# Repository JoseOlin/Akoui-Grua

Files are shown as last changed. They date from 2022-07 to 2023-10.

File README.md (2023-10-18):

# Akoui Transfer Crane

The *Akoui* crane is [Olin Robotics](https://www.olinrobotics.com)' proposal for independent transfer of people with disabilities.

Person moving from wheelchair to bed with electronic assist lift

The Akoui belongs to the **Olin Autonomy** project; an ecosystem of assistive devices to allow independent living for people with disabilities, even severe ones, who can control a joystick.

---

The Akoui crane is made up of 3 modules:

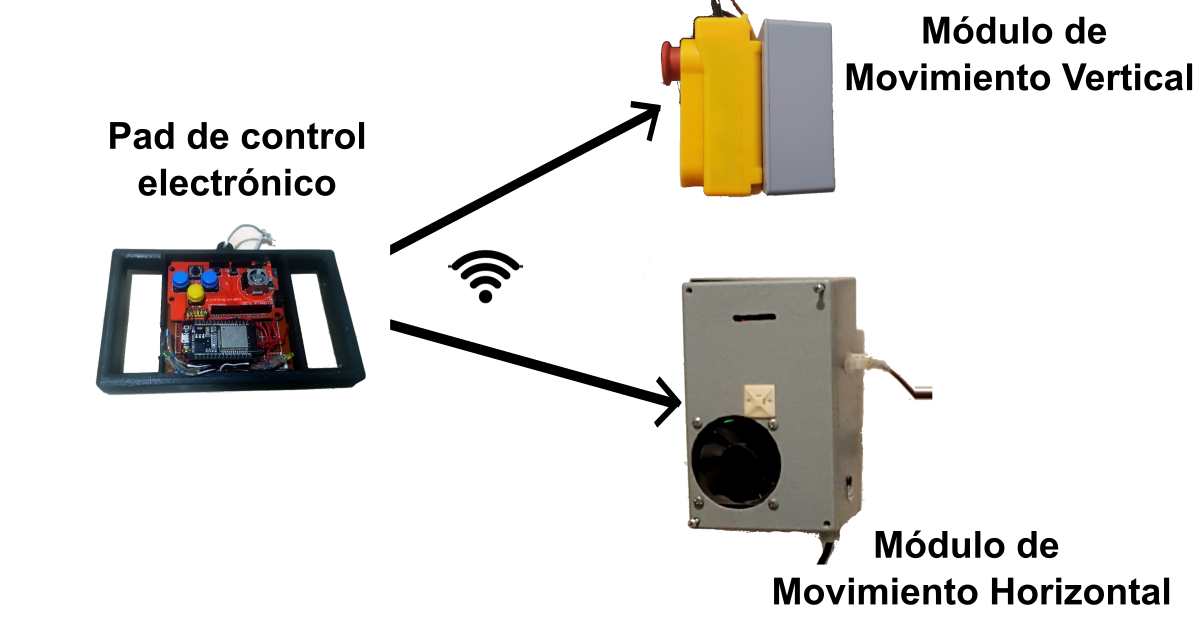
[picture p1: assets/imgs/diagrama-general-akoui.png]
Diagrama General Akoui


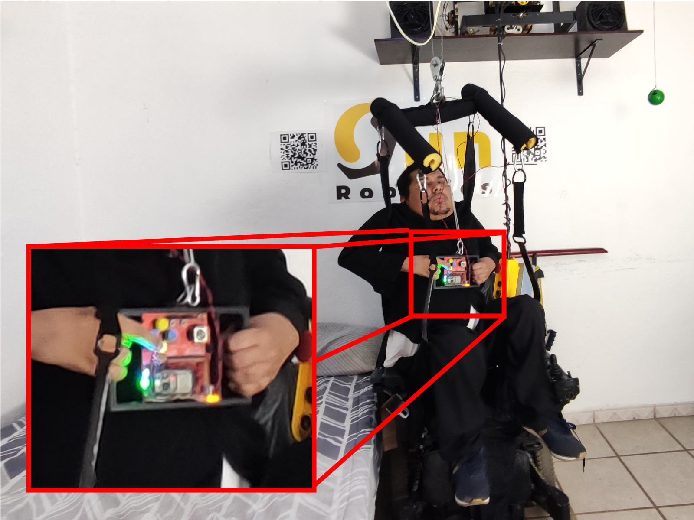
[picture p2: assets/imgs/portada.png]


1. **Vertical motion module**. Electronically controls the vertical movement of the crane. It has an ESP8266 module (WeMos D1 Mini).

2. **Horizontal movement module**. Electronically controls the horizontal movement of the crane. It has an ESP8266 module (WeMos D1 Mini).

3. **Control pad**. Sends movement commands to the respective modules. Uses an ESP-32 module (ESP-WROOM-32).

There is a [tutorial to build it](https://olinrobotics.com/blog/23-09_akoui-construccion-control-pad/p) on the Olin Robotics blog (in Spanish).

---
The Akoui is Free Hardware and Software. We believe in a world where technology for independent living is accessible and free.

If you want to support the development of Akoui, join the [Dojo of Autonomy on Patreon](https://www.patreon.com/olinrobotics?fan_landing=true).

**¡Hasta la Autonomía, Siempre!**
*Always to Autonomy!*

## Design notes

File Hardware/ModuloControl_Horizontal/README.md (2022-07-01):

El módulo de control horizontal se compone de 

- Un regulador de voltaje de 24 a 3.3V
- Un Driver DC MC33926
-

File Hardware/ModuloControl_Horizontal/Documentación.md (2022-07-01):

# Grúa Incorporación

La fuente de poder es de 24V. Conectada a:

	+ Puente H para el motor.
	+ Potenciómetro -> Abanico de la caja
	+ Regulalador de voltaje LM2596

El regulador de voltaje LM2596 recibe 24V en In y entrega 3.3V en Out). Está conectado a:

+ Módulo ESP01

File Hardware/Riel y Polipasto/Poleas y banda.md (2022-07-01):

[Polea Dentada Gt2 60 Dientes 8mm, Ideal Para Nema 23 Cnc,](https://articulo.mercadolibre.com.mx/MLM-582137986-polea-dentada-gt2-60-dientes-8mm-ideal-para-nema-23-cnc-_JM)

[Polea Dentada Gt2 20 Dientes 8mm Nema 23 Impresora3d Cnc 1pz](https://articulo.mercadolibre.com.mx/MLM-585223447-polea-dentada-gt2-20-dientes-8mm-nema-23-impresora3d-cnc-1pz-_JM)

[Polea Pasiva Gt2 20 Dientes Agujero 3mm, Cnc, 3d Print](https://articulo.mercadolibre.com.mx/MLM-585659330-polea-pasiva-gt2-20-dientes-agujero-3mm-cnc-3d-print-_JM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)

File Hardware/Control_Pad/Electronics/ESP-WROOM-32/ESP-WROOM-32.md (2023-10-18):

# ESP-WROOM-32

https://randomnerdtutorials.com/getting-started-with-esp32/

## Pinout

ESP32-Pinout


https://circuits4you.com/2018/12/31/esp32-devkit-esp32-wroom-gpio-pinout/

### Arduino Framework
En Arduino el pin corresponde con el GPIO. 

| Etiqueta	| GPIO		| Pin Framework Arduino |
|---|---|---|
|D2			|	GPIO2 	|  2 	|
|D4			|	GPIO4 	|  4 	|
|D5			|	GPIO5 	|  5 	|
|D18			|	GPIO18	|  18 	|
|D19			|	GPIO19 	|  19 	|
| ...		|	...		|  ...	|

	pinMode(4, OUTPUT);

### NOTAS:

El **GPIO12** (**D12** en el etiquetado de la tablilla) **no debe estar en alto en el arranque**, pues causa conflicto de escritura en la memoria Flash.

	if(Serial.available() > 0)
	  {
	    char c = Serial.read();
	    
	    if (c == 'o')
	    {
	      Serial.println("Activando subida...");
	      String subir_activar = serverNameV + "/subir/1";
	      httpRequest(subir_activar);
	      
	    }
	    else if(c == 'f')
	    {
	      Serial.println("Desactivando subida...");
	      String subir_desactivar = serverNameV + "/subir/0";
	      httpRequest(subir_desactivar);
	    }
	}

## How to power

https://techexplorations.com/guides/esp32/begin/power/

## PlatformIO Board name
esp32dev

[env:esp_wroom_32]
platform = espressif32
board = esp32dev
framework = arduino
monitor_speed = 115200

## Hall Effect Sensor

https://randomnerdtutorials.com/esp32-hall-effect-sensor/

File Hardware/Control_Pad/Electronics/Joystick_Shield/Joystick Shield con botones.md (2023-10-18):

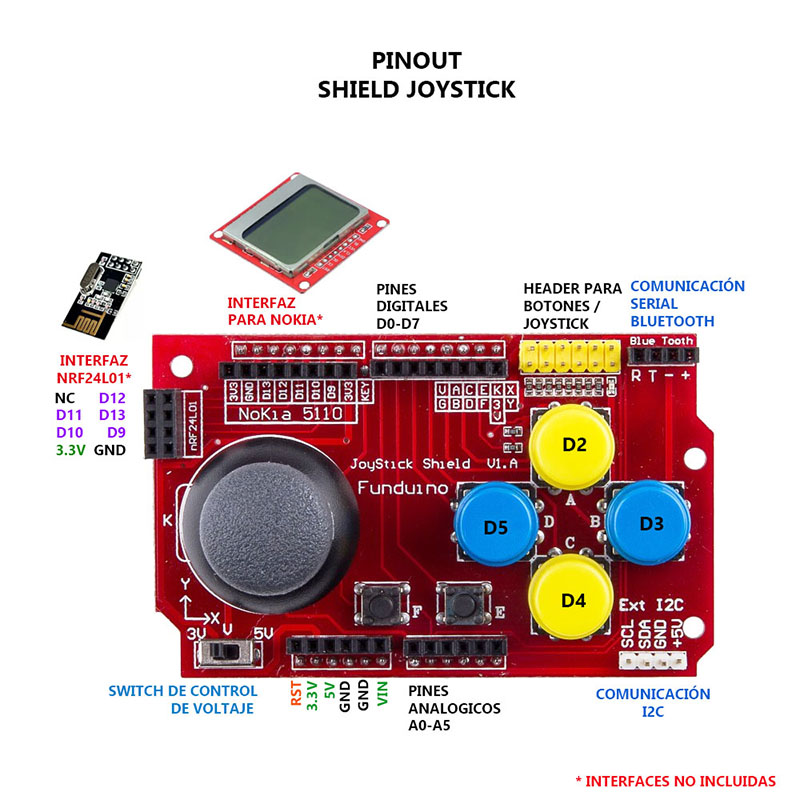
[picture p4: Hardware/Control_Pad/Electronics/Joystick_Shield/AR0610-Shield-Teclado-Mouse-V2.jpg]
AR0610-Shield-Teclado-Mouse-V2

[Liga de Afiliado Amazon](https://amzn.to/46x2H1U)

## Conectores

### Nokia 5110

3v3 GND D13  D12 D11 D10 D9 3V3  KEY    |   F    E    D    C    B    A   NI   NI

RST  3V3 5V GND  GND  VIN   |    JX=A0     JY=A1    A2   A3    A4    A5

NI: No Identificado.

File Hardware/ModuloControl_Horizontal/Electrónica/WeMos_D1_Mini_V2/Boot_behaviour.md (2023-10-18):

D3 está en 0 y pasa a cerca de 2V durante el boot

D1 está en cerca de 2V y pasa a 0V durante el boot

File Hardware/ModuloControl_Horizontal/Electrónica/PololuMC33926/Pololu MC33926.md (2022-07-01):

# MC33926
[Dual MC33926 Motor Driver Carrier](https://www.pololu.com/product/1213)

This dual brushed DC motor driver, based on Freescale’s MC33926 full H-bridge, has a wide operating range of 5 V to 28 V and can deliver almost 3 A continuously (5 A peak) to each of its two motor channels. The MC33926 works with 3 V to 5 V logic levels, supports ultrasonic (up to 20 kHz) PWM, and features current feedback, under-voltage protection, over-current protection, and over-temperature protection.

0J1889.350

## Conexión rápida
### Para usar como control On/Off

- **IN1 e IN2** controlan la dirección.
- **EN**  puenteado a **HIGH**, cuando está en bajo pone los drivers en modo de bajo consumo.
- **D1 puenteado a GND**
- **D2 puenteado a HIGH**.
- **VDD** debe ser alimentado con 3 a 5V  del microcontrolador.

### Para usar con PWM

- IN1 e IN2 controlan la dirección
- D2 recibe la señal de PWM
- **D1 debe estar a tierra para que no interfiera con D2** (ya que este pin también puede recibir PWM pero es más usual ponerlo en D2).
- **EN** puenteado a HIGH (Está por defecto en bajo, poniendo el puente en modo de bajo consumo).
- VDD conectado al voltaje del microcontrolador

### Otros pines útiles
**INV**: Si está puenteado invierte el comportamiento de IN1 e IN2.

**SF**: Status flag. Normalmente alta. Pasará  a bajo si hay sobrecorriente (corto) o sobretemperatura. También pasa a bajo cuando D1 o D2 deshabilitan las entradas. Está debilmente conectada a HIGH así que no puede conectarse un LED, sólo puede leerse desde un microcontrolador.

**FB**: 525 mV por amper. Para estimar la corriente consumida.

## Basic Application Connections
In a typical application, **five I/O lines are used** to connect each motor driver channel to a microcontroller: the two input lines, IN1 and IN2, for direction control, one of the disable lines, D1 or D2, for PWM speed control, the current sense output, FB, for monitoring motor current draw (connected to an analog-to-digital converter input) and the status flag, SF, for monitoring motor driver errors. 

The **control lines can be reduced to two pins per channel** if PWM signals are applied directly to the two input pins with both disable pins held inactive. In each of these cases, the other unused lines must be set to enable proper operation. For example, if D2 is used for the PWM input (as is typically the case), D1 must be held low to prevent it from disabling the motor driver. The circuit board provides convenient jumper points for overriding the motor driver defaults without having to connect extra wires to the module.

The current sense and status flag connections are optional, though monitoring of the status flags can allow detection of latched fault conditions. The status flags are open-drain output, so the two status flag can be wired together for applications where I/O pins are scarce and determining which motor driver is experiencing a fault condition is not necessary.

Note that the default state of the enable pin, EN, is LOW, which holds both motor driver chips in a low-current sleep mode. You will need to hold this pin high (either with an external connection or via the default-overriding jumper next to the pin) to allow the board to run.

## Pinout detallado
 

The default states of many of the MC33926 logic input pins requires that many external connections be made to use this board. 

To reduce the number of necessary external connections, the board has seven default-overriding jumpers. All of the default-overriding jumpers are tied to VDD, except the D1 jumpers, which are tied to GND. 

All **VDD jumper** pads **are circles**; the **ground jumper** pads **are square**. 

Note that the board has only one invert, slew, and enable pin; each of these three pins affects both motor drivers.

| 	**PIN**	|	**Default State**	|	**Description**	|
|---|---|---|
|	**VIN**		|	HIGH			| This is the main 5 V to 28 V motor power supply connection, which should typically be made to the larger VIN pad. Operation from 5 V to 8 V reduces maximum current output; the device is also protected for transients up to 40 V. The smaller VIN pad can be used to distribute the VIN node to the rest of the application circuit; for lower-current applications, the pin can also be used to power the board and motors.|
|	**GND**	| LOW	|	Ground connection for logic and motor power supplies.|
|	**OUT2**	|	HIGH	|	The motor output pin controlled by IN2.	|
|	**OUT1**	|	HIGH	|	The motor output pin controlled by IN1. |
|	**VDD**		|	HIGH	|	3V to 5V logic supply connection. This pin is used only for the SF pull-up and default-overriding jumpers; in the rare case where none of those features is used, VDD can be left disconnected. |
|	**IN2**		|	HIGH	|	The logic input control of OUT2. PWM can be applied to this pin (typically done with both disable lines inactive). <br>IN2: HIGH -> OUT2: V_PWR (VIN)<br />IN2: LOW -> OUT2: PGND |
|	**IN1**		|	HIGH	|	The logic input control of OUT1. PWM can be applied to this pin (typically done with both disable lines inactive).<br /> IN1: HIGH -> OUT1:VIN<br /> |
|	**PWM / D2**	|	LOW	 |	Inverted disable input: when D2 is low, OUT1 and OUT2 are set to high impedance. A D2 PWM duty cycle of 70% gives a motor duty cycle of 70%. Typically, only one of the two disable pins is used, but the default is for both disable pins to be active. |
|	**PWM / D1**	|	HIGH	|	Disable input: when D1 is high, OUT1 and OUT2 are set to high impedance. A D1 PWM duty cycle of 70% gives a motor duty cycle of 30%. Typically, only one of the two disable pins is used, but the default is for both disable pins to be active. |
|	**SF**	|	HIGH	|	Status flag output: an over-current (short circuit) or over-temperature event will cause SF to be latched LOW. If either of the disable pins (D1 or D2) are disabling the outputs, SF will also be LOW. Otherwise, this pin is weakly pulled high. This allows the two SF pins on the board to be tied together and connected to a single MCU input. |
|	**FB**	|	LOW	|	The FB output provides analog current-sense feedback of approximately 525 mV per amp (only active while H-bridge is driving). |
|	**EN**	|	LOW	|	Enable input: when EN is LOW, the both motor driver ICs are in a low-current sleep mode. |
|	**SLEW**	|	LOW	|	Output slew rate selection input. A logical LOW results in a slow output rise time (1.5 μs to 6 μs). A logical HIGH selects a fast output rise time (0.2 μs to 1.45 μs). This pin should be set HIGH for high-frequency (over 10 kHz) PWM. This pin determines the slew rate mode for both motor driver ICs. 	|
|	**INV**		|	LOW	| A logical high value inverts the meaning of IN1 and IN2 for both motor drivers.<br>Cuando INV=LOW, IN1=LOW $\rightarrow$ OUT1=GND<br>Cuando INV=HIGH, IN1=LOW $\rightarrow$ OUT1=VIN, |

## MC33926 Motor Driver Carrier (Liga Pololu)

Es la opción single del driver.**

https://www.pololu.com/product/1212

17.95  USD

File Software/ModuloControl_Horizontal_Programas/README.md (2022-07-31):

## Grua_Horizontal_ESP_Station
El módulo se configura como un **servidor HTTP en modo Station**, esto es, requiere un módem y una red a la cual conectarse, a través de la cual se conectan los clientes

## Grua_Horizontal_ESP_AP
Versión en desarrollo que funciona como **Access Point**, es decir, no requerirá módem, el ESP genera una red con contraseña a la que los clientes pueden conectarse directamente.

## Grua_Horizontal_Arduino_ESP_TCP_Station
Versión que incluye un Arduino Nano, que permitirá hacer un control más fino del movimiento

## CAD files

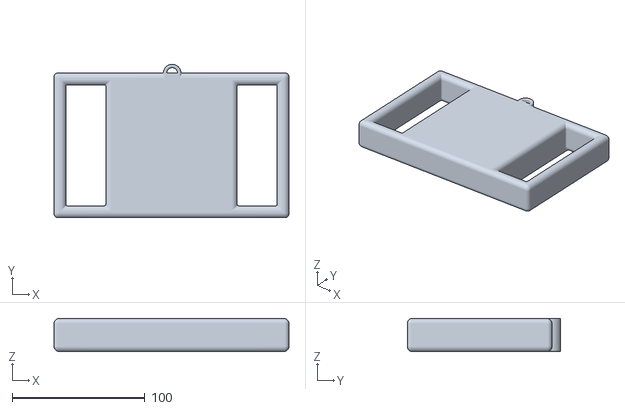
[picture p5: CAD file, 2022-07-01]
Hardware/Control_Pad/3D_Pieces/Cubierta_Control/ControlPad_Bottom_v3.stl
177.0 x 115.6 x 25.0

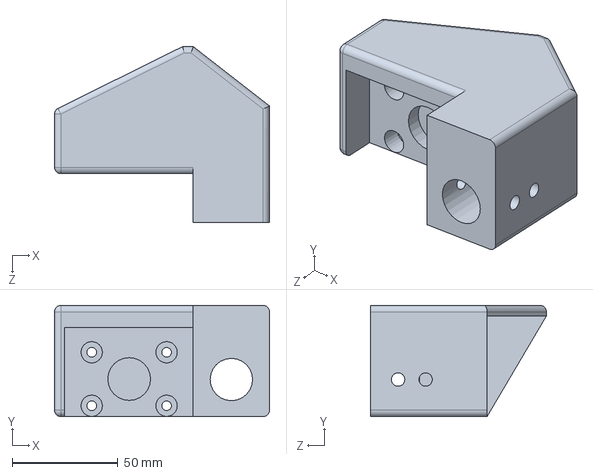
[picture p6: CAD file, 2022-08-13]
Hardware/Sujecion_Automatica/Sujeta_motor_grua_editada.SLDPRT
101.5 x 52.5 x 83.0 mm

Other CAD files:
Hardware/Control_Pad/3D_Pieces/Cubierta_Control/Cubierta_Control_Bottom.FCStd
Hardware/Sujecion_Automatica/Sujeta_motor_grua_editada.STL

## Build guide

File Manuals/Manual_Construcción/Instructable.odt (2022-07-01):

Hace algo así como doce años que no puedo levantarme de la cama sin asistencia de alguien más. Hay una serie de pequeños placeres

# Materials

## Movimiento Vertical

440 lb Electric Wire Hoist. $3,899

Better configured as double line lift, cause the single line is a little fast.

https://steeldragontools.com/products/cable-wire-hoist/sdt-ewh0440/

https://www.amazon.com.mx/herramientas-440-libras-polipasto-el%C3%A9ctrico-distancia/dp/B00W86NR68

https://articulo.mercadolibre.com.mx/MLM-594135734-mini-grua-electrica-400-libras-control-remoto-con-cable-j-_JM

Riel superior para Portón con cerretilla. $1,200

Modulo Relevadores Relay 4 Canales 5v $64

https://articulo.mercadolibre.com.mx/MLM-601622312-modulo-relevadores-relay-4-canales-5v-_JM

Modulo Adaptador Usb Serial Para Wifi Esp8266 Esp-01 Arduino $34

https://articulo.mercadolibre.com.mx/MLM-660629365-modulo-adaptador-usb-serial-para-wifi-esp8266-esp-01-arduino-_JM

Modulo Wifi Serial Esp8266 Arduino $62.10

https://articulo.mercadolibre.com.mx/MLM-632013093-modulo-wifi-serial-esp8266-arduino-_JM

Placa Fenólica Perforada Tipo Protoboard De 7 Cm X 14,5 Cm $65.00

https://www.steren.com.mx/placa-fenolica-perforada-tipo-protoboard-de-7-cm-x-14-5-cm.html

Convertidor Dc-dc Lm2596 $40

https://articulo.mercadolibre.com.mx/MLM-586810049-convertidor-dc-dc-lm2596-_JM

Gabinete plástico de 15 x 6 x 9.9 cm $99.00

https://www.steren.com.mx/gabinete-plastico-de-15-x-6-x-9-9-cm.html

## Movimiento Horizontal

Motor de 24V, con caja reductora. Tipo U. $45 USD

Fuente Conmutada De Alimentación 12v 5a 60w, 110/220vca $184

https://articulo.mercadolibre.com.mx/MLM-614165953-fuente-conmutada-de-alimentacion-12v-5a-60w-110220vca-_JM

Gabinete plástico de 18 x 6.5 x 11 cm $120

https://www.steren.com.mx/gabinete-plastico-de-18-x-6-5-x-11-cm.html

Polea Dentada Gt2 60 Dientes 8mm, Ideal Para Nema 23 Cnc, $130

https://articulo.mercadolibre.com.mx/MLM-582137986-polea-dentada-gt2-60-dientes-8mm-ideal-para-nema-23-cnc-_JM

Kit 2 Poleas Gt2 5mm Con 5m Banda Reprap Cnc Impresora 3d $264

https://articulo.mercadolibre.com.mx/MLM-661051453-kit-2-poleas-gt2-5mm-con-5m-banda-reprap-cnc-impresora-3d-_JM

Endstop Switch Limit Fin Carrera Reprap Impresora 3d $36.95

https://articulo.mercadolibre.com.mx/MLM-551738363-endstop-switch-limit-fin-carrera-reprap-impresora-3d-_JM

2 x Modulo Wifi Serial Esp8266 Arduino $62.10 c/u

https://articulo.mercadolibre.com.mx/MLM-632013093-modulo-wifi-serial-esp8266-arduino-_JM

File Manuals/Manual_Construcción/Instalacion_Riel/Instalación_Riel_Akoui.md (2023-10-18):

[TOC] 

# Instalación de riel y polipasto
En este post documentamos el proceso de instalación del riel para una grúa para traslado. 
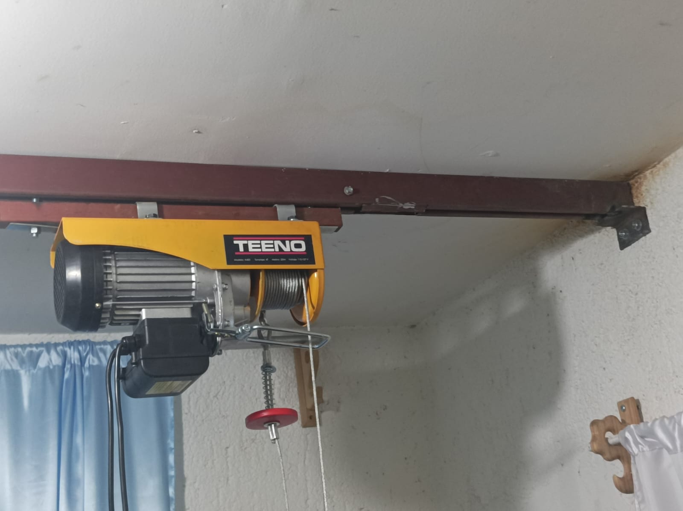
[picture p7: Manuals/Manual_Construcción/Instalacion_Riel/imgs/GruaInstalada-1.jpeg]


# Materiales
+ 1 x Riel para portón 1500

+ 2 x Soportes angulares
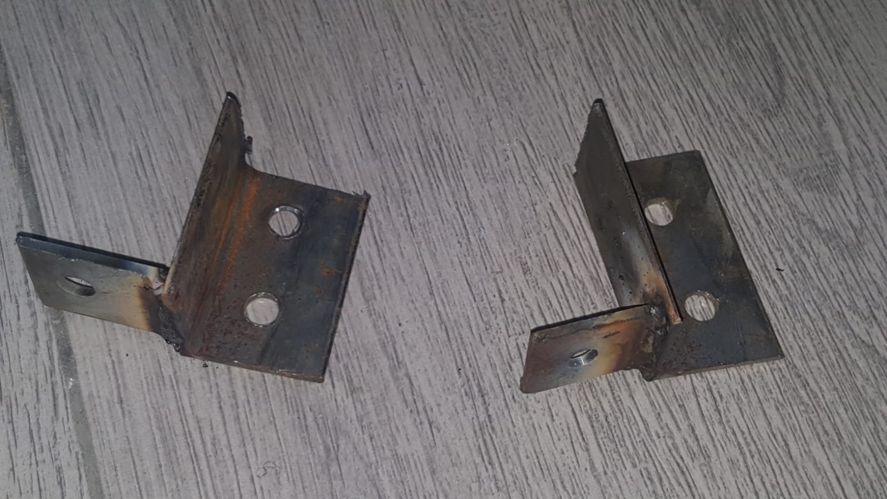
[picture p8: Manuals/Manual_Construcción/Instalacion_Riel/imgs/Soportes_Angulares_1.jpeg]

+ 4 x Taquete de 3/8 de acero con tornillo.
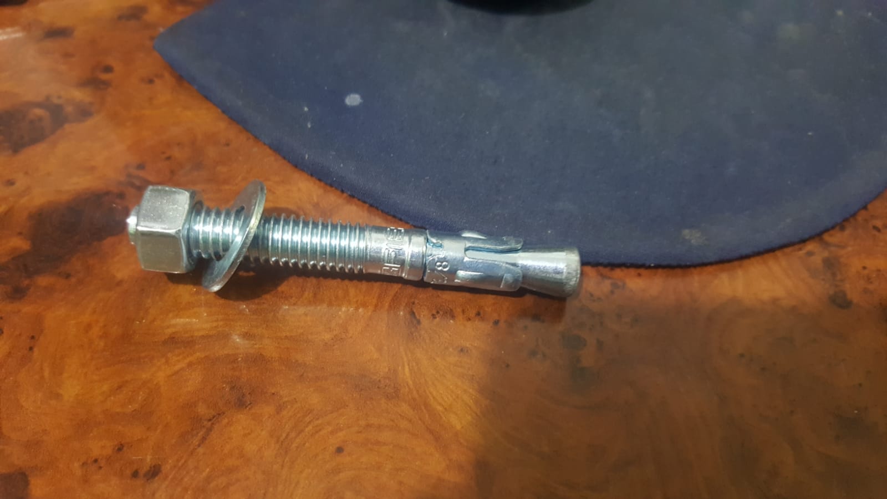
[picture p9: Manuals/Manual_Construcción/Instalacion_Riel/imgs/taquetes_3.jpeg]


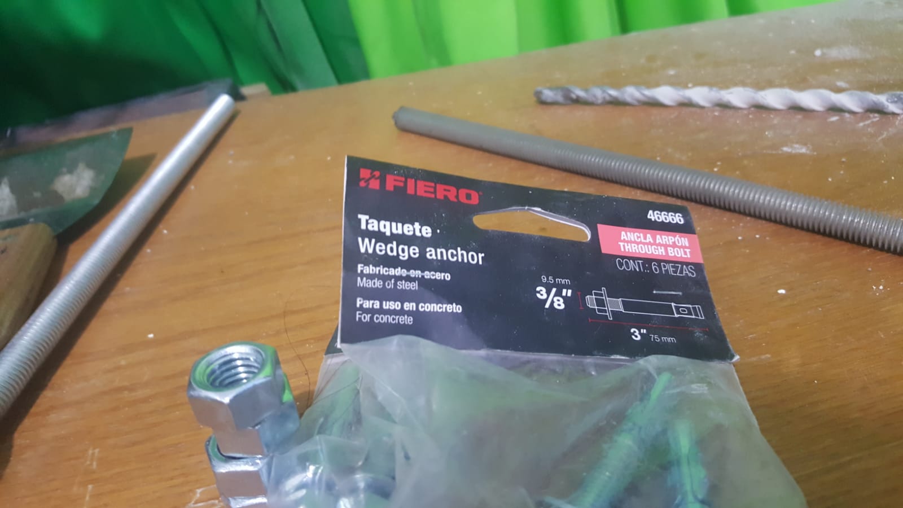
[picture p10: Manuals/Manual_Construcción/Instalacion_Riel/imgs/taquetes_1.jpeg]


+ 1 x Sistema de Rodamiento aéreo para riel

## Soportes angulares
Construidos con placa de 1/8". Barrenos de 3/8".
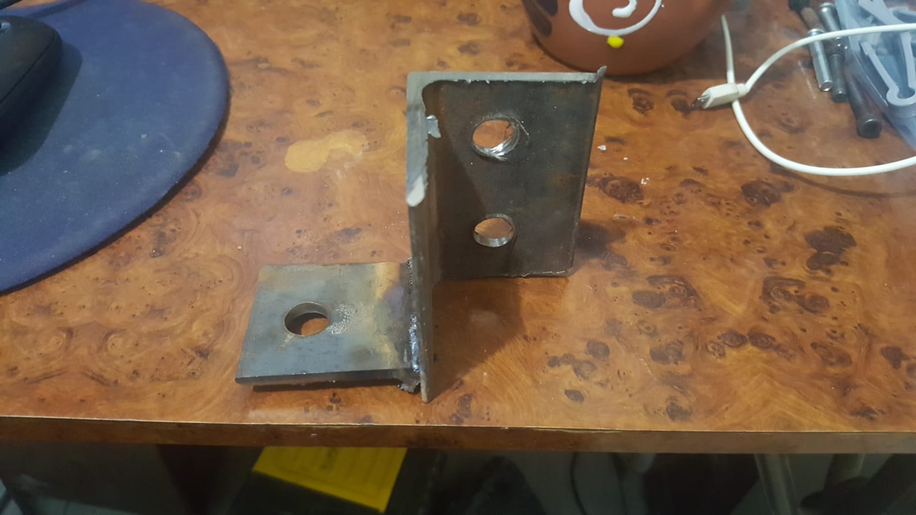
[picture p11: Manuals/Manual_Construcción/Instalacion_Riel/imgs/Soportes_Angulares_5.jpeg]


# Instrucciones

## 1. Instalar los soportes angulares

Los soportes angulares se colocan en la pared y son los que sostienen el riel.



Para colocar los soportes angulares usaremos los taquetes de acero. El taquete debe **instalarse en una dala o castillo**. 

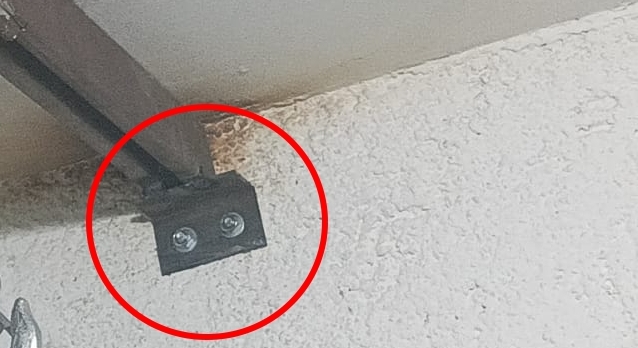
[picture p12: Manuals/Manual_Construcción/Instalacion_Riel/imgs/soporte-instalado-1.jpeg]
Soporte instalado


**NOTA**: En caso de que no hubiera una dala o castillo accesible lo recomendable sería colocar los soportes angulares con tornillos que atraviesen la pared (revisar apéndice).

Una vez instalados ambos soportes angulares se coloca el riel encima de los mismos.
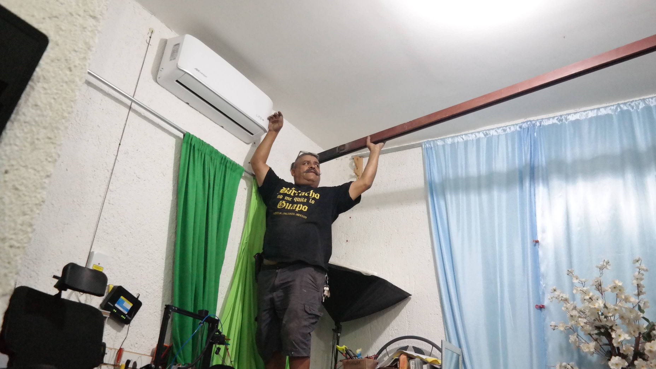
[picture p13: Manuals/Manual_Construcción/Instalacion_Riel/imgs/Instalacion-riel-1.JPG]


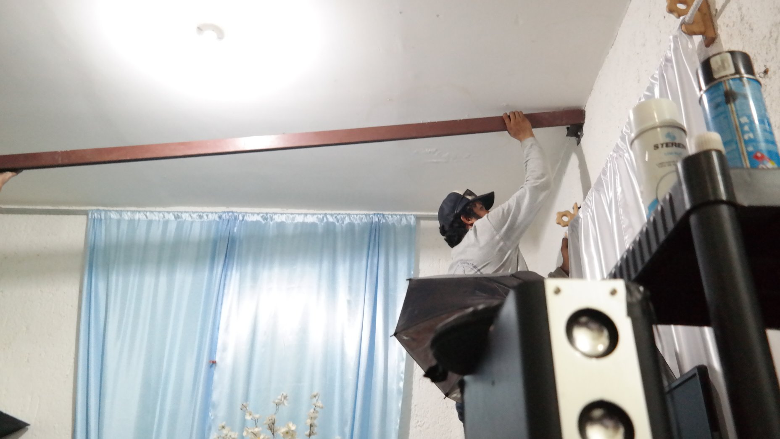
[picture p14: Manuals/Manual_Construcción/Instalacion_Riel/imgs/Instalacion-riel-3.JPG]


Una vez colocado el riel, puede sujetarse con un tornillo pasado, con rosca de seguridad o soldarse directamente al soporte angular.

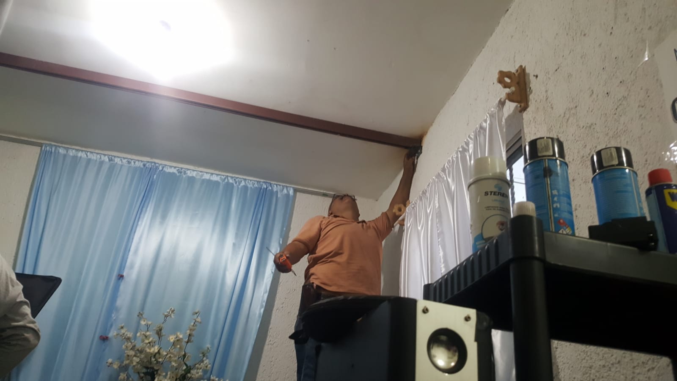
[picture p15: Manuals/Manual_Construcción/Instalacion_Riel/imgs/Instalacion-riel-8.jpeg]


## Colocación del polipasto
Para colocar el polipasto debe hacerse un corte en el riel, que permita que los rodamientos del polipasto entren por debajo del riel.

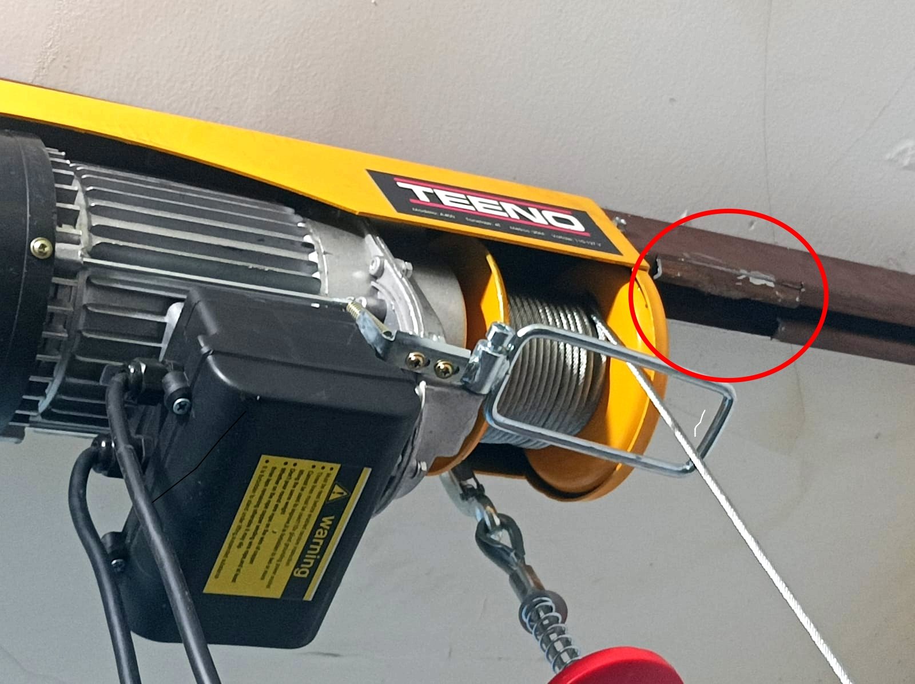
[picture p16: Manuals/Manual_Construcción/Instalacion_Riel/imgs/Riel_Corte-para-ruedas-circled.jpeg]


Una vez que se coloca el polipasto se coloca un tornillo atravesado en el riel, antes del corte, para garantizar que el polipasto no llegue a esa sección del riel.
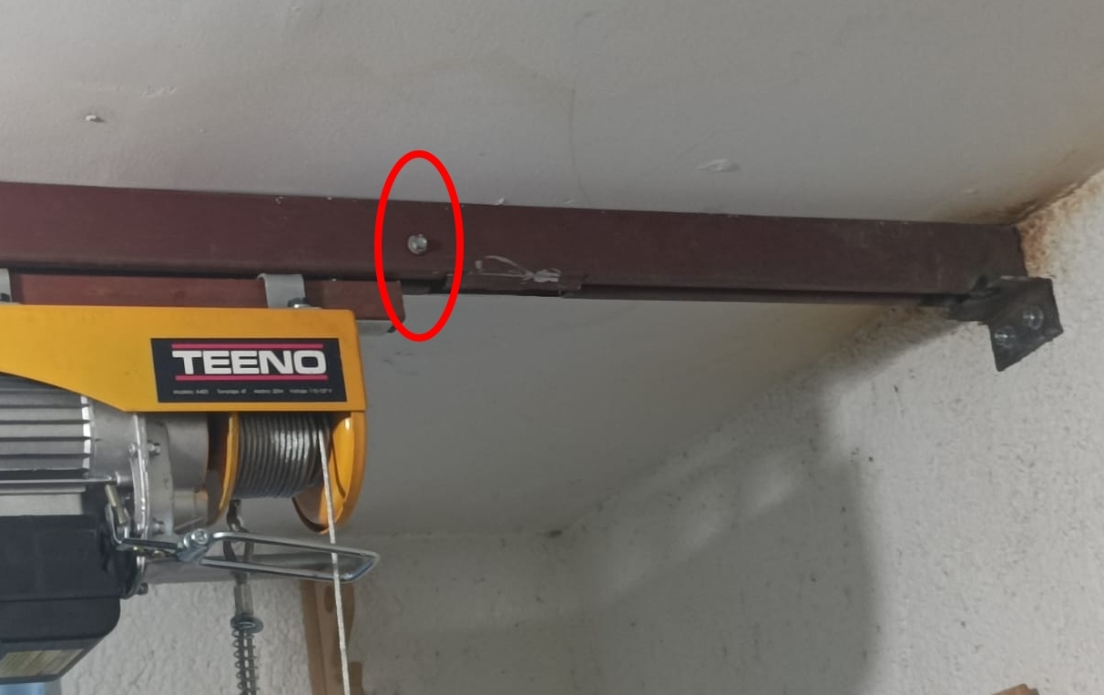
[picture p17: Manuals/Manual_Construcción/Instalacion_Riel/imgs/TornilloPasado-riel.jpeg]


# Apéndices
## Cómo colocar el soporte angular con tornillos atravesando la pared

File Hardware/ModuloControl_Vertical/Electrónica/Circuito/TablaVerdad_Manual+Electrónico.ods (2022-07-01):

A1 | B1 | A2 | B2 | L | N-B | Abajo | Arriba
0 | 0 | 0 | 0 | 0 | 0 | 0 | 0
0 | 0 | 0 | 0 | 0 | 1 | 0 | 0
0 | 0 | 0 | 0 | 1 | 0 | 0 | 0
0 | 0 | 0 | 0 | 1 | 1 | 0 | 0
0 | 0 | 0 | 1 | 0 | 0 | 0 | 0
0 | 0 | 0 | 1 | 0 | 1 | 1 | 0
0 | 0 | 0 | 1 | 1 | 0 | 0 | 0
0 | 0 | 0 | 1 | 1 | 1 | 1 | 0
0 | 0 | 1 | 0 | 0 | 0 | 0 | 1
0 | 0 | 1 | 0 | 0 | 1 | 0 | 1
0 | 0 | 1 | 0 | 1 | 0 | 0 | 0
0 | 0 | 1 | 0 | 1 | 1 | 0 | 0
0 | 0 | 1 | 1 | 0 | 0 | 0 | 1
0 | 0 | 1 | 1 | 0 | 1 | 0 | 1
0 | 0 | 1 | 1 | 1 | 0 | 0 | 0
0 | 0 | 1 | 1 | 1 | 1 | 0 | 0
0 | 1 | 0 | 0 | 0 | 0 | 1 | 0
0 | 1 | 0 | 0 | 0 | 1 | 1 | 0
0 | 1 | 0 | 0 | 1 | 0 | 1 | 0
0 | 1 | 0 | 0 | 1 | 1 | 1 | 0
0 | 1 | 0 | 1 | 0 | 0 | 1 | 0
0 | 1 | 0 | 1 | 0 | 1 | 1 | 0
0 | 1 | 0 | 1 | 1 | 0 | 1 | 0
0 | 1 | 0 | 1 | 1 | 1 | 1 | 0
0 | 1 | 1 | 0 | 0 | 0 | 0 | 1
0 | 1 | 1 | 0 | 0 | 1 | 1 | 0
0 | 1 | 1 | 0 | 1 | 0 | 0 | 0
0 | 1 | 1 | 0 | 1 | 1 | 0 | 0
0 | 1 | 1 | 1 | 0 | 0 | 0 | 1
0 | 1 | 1 | 1 | 0 | 1 | 0 | 1
0 | 1 | 1 | 1 | 1 | 0 | 0 | 0
0 | 1 | 1 | 1 | 1 | 1 | 0 | 0
1 | 0 | 0 | 0 | 0 | 0 | 0 | 1
1 | 0 | 0 | 0 | 0 | 1 | 0 | 1
1 | 0 | 0 | 0 | 1 | 0 | 0 | 0
1 | 0 | 0 | 0 | 1 | 1 | 0 | 0
1 | 0 | 0 | 1 | 0 | 0 | 1 | 0
1 | 0 | 0 | 1 | 0 | 1 | 1 | 0
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

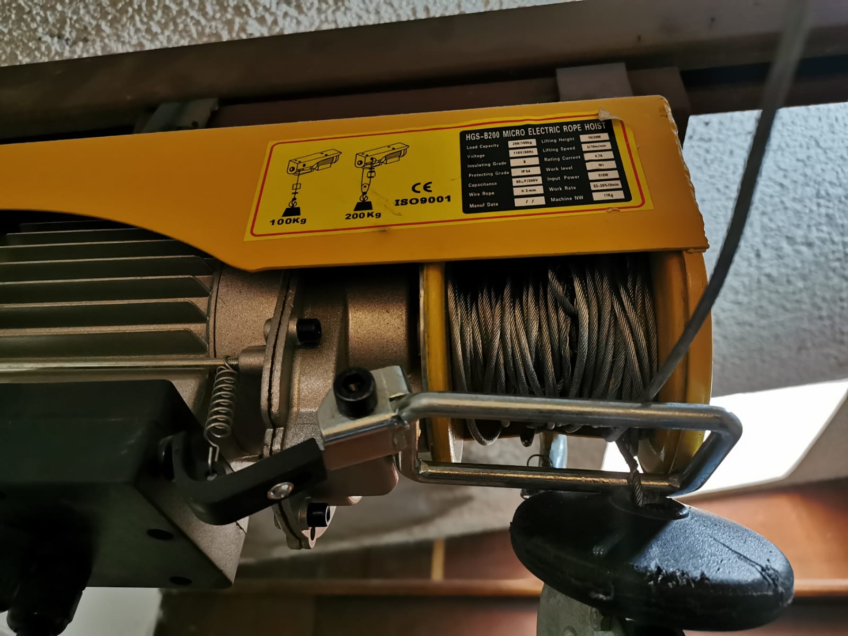
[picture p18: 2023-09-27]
Manuals/Manual_Mantenimiento/imgs/f345957a-56fa-49c0-8a02-a49b8b5b43ea.jpeg

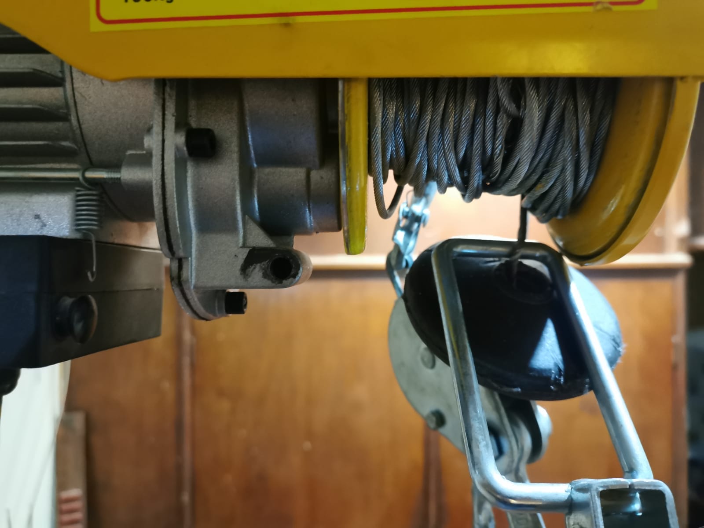
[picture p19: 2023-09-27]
Manuals/Manual_Mantenimiento/imgs/69068aa0-dca3-4af3-bbdf-f4009228d81e.jpeg

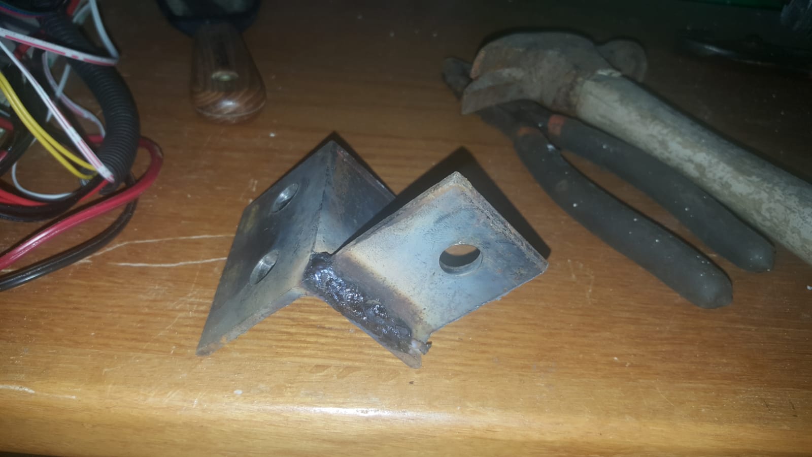
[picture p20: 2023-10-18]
Manuals/Manual_Construcción/Instalacion_Riel/imgs/Soportes_Angulares_10.jpeg

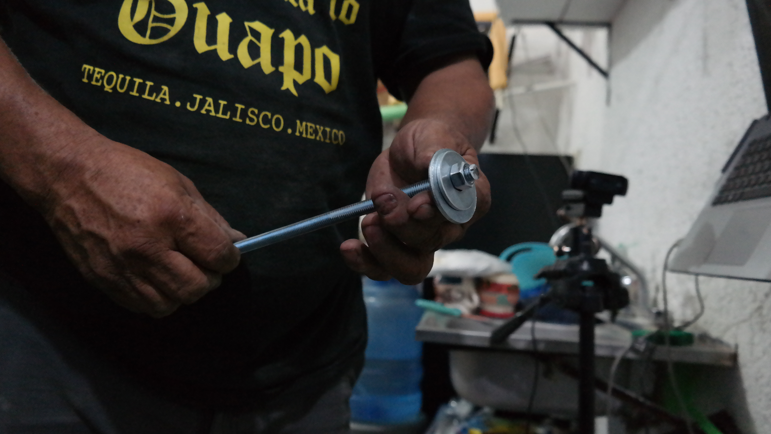
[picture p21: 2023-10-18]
Manuals/Manual_Construcción/Instalacion_Riel/imgs/Tornillo_3-8_Recortado_2.JPG

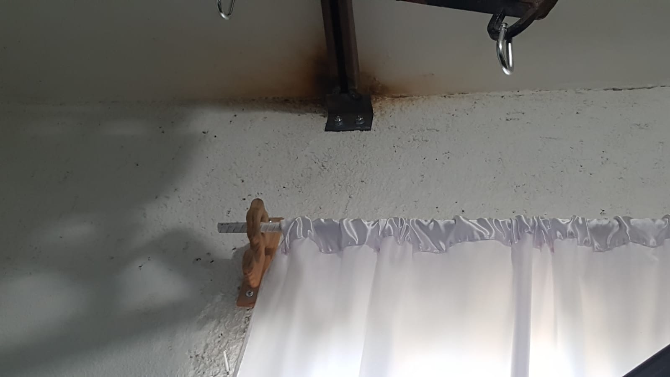
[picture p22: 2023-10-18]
Manuals/Manual_Construcción/Instalacion_Riel/imgs/Soporte-Angular-Instalado_2.jpeg

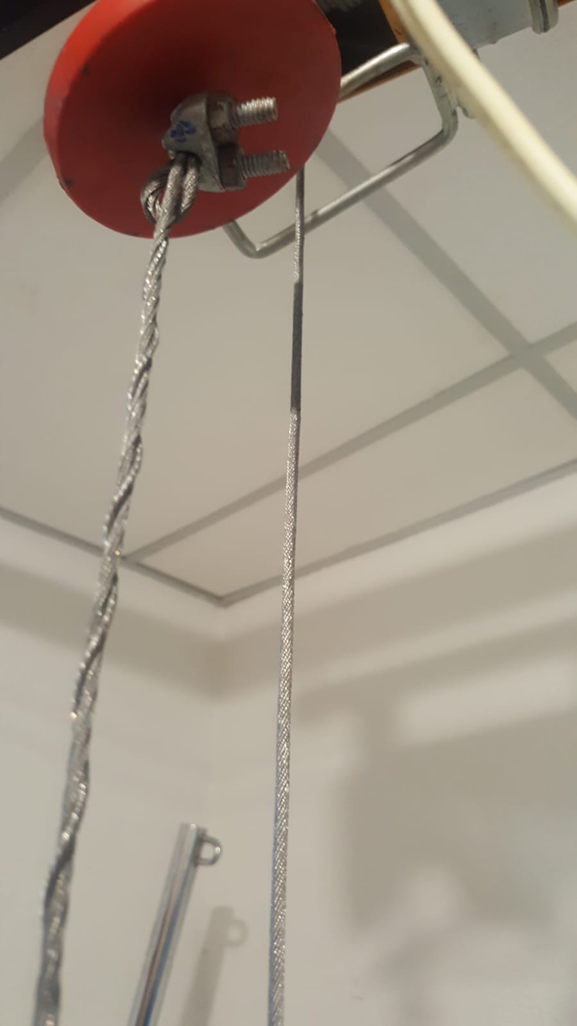
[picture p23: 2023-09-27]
Manuals/Manual_Mantenimiento/imgs/8d66d0f0-94e8-4612-b5ec-0b52ff6adaa5.jpeg

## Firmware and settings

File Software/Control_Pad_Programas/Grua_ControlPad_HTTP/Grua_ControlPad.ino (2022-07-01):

/* Este programa lee los botones y el joystick del Joystick Shield para controlar la grúa. 


 Los números de pin corresponden con el número de GPIO en el WROOOM (morados en el pinOut), 
que corresponde con la etiqueta en la tablilla (D13 = GPIO13, etc.)

Los pines digitales en el Joystick Shield (no etiquetados) tienen la siguiente configuración
  A
D   B
  C

Su conexión al ESP32 WROOM es la siguiente
 F  E   D  C  B   A 
 A: 13
 B: 15
 C: 14
 D: 27
 E: 33 
 F: 32

 X: 35 
 Y: 34
 K: No conectado, es el botón del joystick.

  Los botones del joystick shield tienen resistencias pull-up, por lo tanto son activos en bajo.
 El pin 12 no se utilizó como GPIO pues debe estar en LOW en el arranque, y los botones tienen resistencias pull-up incorporadas.
 Se saltó el 12 y se usó el 15.

 El programa es para un ESP-WROM-32. 
 + Placa:  ESP32 Arduino -> ESP32 Dev Module.
  
  NOTA: (Para usar la tarjeta hay que instalar las librerías manualmente).
*/

#include <WiFi.h>
#include <HTTPClient.h>

const char* ssid = "GomezTorres";
const char* password = "lucy1nthesky";

String serverNameV = "http://192.168.1.69"; // Dirección del ESP para el movimiento vertical
String serverNameH = "http://192.168.1.70"; // Dirección del ESP para el movimiento horizontal

HTTPClient http;


int pinSubir = 13; //C
int pinBajar = 14; //A

int pinIzquierda = 27; //D
int pinDerecha = 15;  //B 

int pinParo = 16; // K

int pinDAC1 = 25; 
int pinDAC2 = 26;

int pinAbrirPinza = 32; //
int pinCerrarPinza = 33; //

int pinJx = 35;
int pinJy = 34;

int Jx_Centro = 1850;
int Jy_Centro = 1870;

int umbralLecturaJoystick = 250;


boolean flagSubiendo = false, flagBajando = false;
boolean flagMoviendoIzq = false, flagMoviendoDer = false;
boolean flagAbriendo = false, flagCerrando = false;
boolean flagParo = false;

unsigned long tiempoUltimaPulsacionParo = 0;
unsigned long umbralLecturaParo =  1000; // El botón de paro se leerá cada 1000 ms.
unsigned int delayLoop = 5; // Procurar que la frecuencia del Pad sea el doble que la de la lectura en los módulos de movimiento.
unsigned int delayRequestParada = 5;

#define comActiva 1
#define comVerbose 1

void setup() 
{
  Serial.begin(115200);
  
  pinMode(pinSubir, INPUT);
  pinMode(pinBajar, INPUT);
  pinMode(pinIzquierda, INPUT);
  pinMode(pinDerecha, INPUT);

  pinMode(pinCerrarPinza, INPUT);
  pinMode(pinAbrirPinza, INPUT);

  pinMode(pinParo, INPUT);
  
  
  http.setConnectTimeout(500); //Tiempo en milisegundos.
   
  WiFi.begin(ssid, password);

  Serial.println("Connecting");
  while(WiFi.status() != WL_CONNECTED) 
  {
    delay(500);
    Serial.print(".");
  }
  
  Serial.println("");
  Serial.print("Connected to WiFi network with IP Address: ");
  Serial.println(WiFi.localIP());

  #if comActiva
  Serial.println("La comunicación WiFi está activa, se enviarán peticiones Http a la Grúa.");
  #else
  Serial.println("La comunicación WiFi está inactiva (Modo de Pruebas), NO se enviarán peticiones Http a la Grúa.");
  #endif
}
 
void loop() 
{
  leerBotones();
  leerJoystick();
  
  delay(delayLoop);
}

void httpRequest(String serverPath)
{
  //int umbralIntentos = 5;
  //int contIntentos = 0;
  if(WiFi.status()== WL_CONNECTED)
  {
    int httpResponseCode;    
                      // IP + path
    if(http.begin(serverPath.c_str() ) )
    {
      http.setConnectTimeout(500);

      //do
      //{
        // Enviar la petición http.
      httpResponseCode = http.GET();

        //contIntentos++;
      //} while(httpResponseCode < 0 || contIntentos < umbralIntentos);    

      #if comVerbose
      if(httpResponseCode > 0)
      {
        String payload = http.getString();
        Serial.println(payload);
      }
      else
      {
        //Serial.print("HTTP GET error ");
        //Serial.println(http.errorToString(httpResponseCode).c_str());
        Serial.printf("[HTTP] GET... failed, error: %s\n", http.errorToString(httpResponseCode).c_str());
      }
      #endif
             
      http.end();
    }
    else
    {
      Serial.println("HTTP unable to connect");
    }
  }
  else{
    Serial.println("No hay conexión");
  }
}

void leerBotones()
{
  // Los botones tienen resistencias pull-up, por lo tanto están activos en Bajo.
  
  int subir = digitalRead(pinSubir);
  int bajar = digitalRead(pinBajar);
  int izquierda = digitalRead(pinIzquierda);
  int derecha = digitalRead(pinDerecha);
  
  int cerrar = digitalRead(pinCerrarPinza);
  int abrir = digitalRead(pinAbrirPinza);

  int paro = digitalRead(pinParo);


  /*if(subir == LOW && !flagSubiendo)
  {
    Serial.println("Activando subida...");
    String subir_activar = serverNameV + "/subir/1";
    //httpRequest(subir_activar);
    flagSubiendo = true;
  }
  else if(subir == HIGH && flagSubiendo)
  {
    Serial.println("Desactivando subida...");
    String subir_desactivar = serverNameV + "/subir/0";
    //httpRequest(subir_desactivar);
    //httpRequest(subir_desactivar);
    flagSubiendo = false;
  }*/

  // Hay tres tipos de validación para el estado de los botones.
  // - Pulso en dos sentidos (presionar y liberar), 
  // - Pulso Escalón (enviar mientras está en alto) y 
  // - Pulso con un sentido (Activa y desactiva con el mismo flanco).
  
  validarEstadoBoton(subir, flagSubiendo, serverNameV, "/subir/");
  validarEstadoBoton(bajar, flagBajando, serverNameV, "/bajar/");
    
  validarEstadoBoton(izquierda, flagMoviendoIzq, serverNameH, "/izquierda/");
  validarEstadoBoton(derecha,   flagMoviendoDer, serverNameH, "/derecha/");
  
  //validarEstadoBoton_Continuo(izquierda, serverNameH, "/izquierda/");
  //validarEstadoBoton_Continuo(derecha, serverNameH, "/derecha/");

  validarBotones_Pinza(abrir,  flagAbriendo, "Abrir");
  validarBotones_Pinza(cerrar, flagCerrando, "Cerrar");


  validarBoton_Paro(paro, flagParo);  
}

void validarEstadoBoton(int &estado, bool &flagActivo, const String serverName, String comando)
{
  if(estado == LOW && !flagActivo)
  {
    #if comVerbose
    Serial.print("Activando "); Serial.println(comando);
    #endif
    
    String comando_Activar = serverName + comando + "1";
    #if comActiva
    httpRequest(comando_Activar);
    #endif
    flagActivo = true;
  }
  else if(estado == HIGH && flagActivo)
  {
    #if comVerbose
    Serial.print("Desactivando "); Serial.println(comando);
    #endif
    
    String comando_Desactivar = serverName + comando + "0";
    
    #if comActiva
    httpRequest(comando_Desactivar);
    delay(delayRequestParada);
    
    httpRequest(comando_Desactivar);
    delay(delayRequestParada);
    
    httpRequest(comando_Desactivar);
    #endif
    
    flagActivo = false;

    //TODO: Probar si es mejor implementar un contador y enviar un Request por ciclo del loop.
  }
}


void validarEstadoBoton_Continuo(int &estado, const String serverName, String comando)
{
  if(estado == LOW)
  {
    Serial.print("Activando "); Serial.println(comando);
    String comando_Activar = serverName + comando + "1";
    #if comActiva
    httpRequest(comando_Activar);
    #endif
  }
  /*else if(estado == HIGH)
  {
    Serial.print("Desactivando "); Serial.println(comando);
    String comando_Desactivar = serverName + comando + "0";
    #if comActiva
    httpRequest(comando_Desactivar);
    #endif
  }*/
}

void validarBotones_Pinza(int estado, bool &flagActivo, String comando)
{
  if(estado == LOW && !flagActivo)
  {
    Serial.print("Activando "); Serial.println(comando);
    //String comando_Activar = serverName + comando + "1";
    flagActivo = true;
  }
  else if(estado == HIGH && flagActivo)
  {
    Serial.print("Desactivando "); Serial.println(comando);
    //String comando_Activar = serverName + comando + "0";
    flagActivo = false;
  }
}


void validarBoton_Paro(int estado, bool &flagActivo)
{
  // La activación y desactivación del paro es con la misma acción del botón, así que debe validarse que una vez leído, el 
  // botón no se vuelva a leer durante cierto periodo.
  unsigned long tiempoActual = millis();
  unsigned long tiempoTranscurrido = tiempoActual - tiempoUltimaPulsacionParo;
  
  if(estado == LOW && flagActivo == false && (tiempoTranscurrido > umbralLecturaParo) )
  {
    String comandoActivarParo_V = serverNameV + "/paro/1";
    String comandoActivarParo_H = serverNameH + "/paro/1";
    Serial.println("Activando paro de emergencia");
     #if comActiva
    httpRequest(comandoActivarParo_V);
    delay(10);
    httpRequest(comandoActivarParo_V);
    
    httpRequest(comandoActivarParo_H);
    delay(10);
    httpRequest(comandoActivarParo_H);
    #endif
    flagActivo = true;
    tiempoUltimaPulsacionParo = millis();
  }
  else if(estado == LOW && flagActivo == true && tiempoTranscurrido > umbralLecturaParo)
  {
    String comandoDesactivarParo_V = serverNameV + "/paro/0";
    String comandoDesactivarParo_H = serverNameH + "/paro/0";
    Serial.println("Desactivando paro de emergencia");
     #if comActiva
    httpRequest(comandoDesactivarParo_V);
    httpRequest(comandoDesactivarParo_H);
    #endif
    flagActivo = false;
    tiempoUltimaPulsacionParo = millis();
  }
}

void leerJoystick()
{
  int JxVal = analogRead(pinJx);
  int JyVal = analogRead(pinJy);

  int JxAbsDif = abs(Jx_Centro - JxVal);
  int JyAbsDif = abs(Jy_Centro - JyVal);
  
  if(JxAbsDif > umbralLecturaJoystick || JyAbsDif > umbralLecturaJoystick)
  {
    Serial.print("Jx: "); Serial.print(JxVal);
    Serial.print(",\tJy: "); Serial.println(JyVal);
  } 
}

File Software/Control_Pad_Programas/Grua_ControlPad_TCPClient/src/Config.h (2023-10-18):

#ifndef CONFIG_H
#define CONFIG_H

#define commActiva 1  // Activa o desactiva la comunicación Wifi.
// Es útil desactivarla para que durante debugueo o prueba de los botones no se
// envíen comandos de movimiento.

// Only one of these two should be active.
#define commTcpActiva 1 // New protocol
#define commHttpActiva 0 // Former protocol

#define commVerbose 1 // Enable INFO messages over UART.
#define DEVMODE 1 // Slow down the setup routine to allow check some values.

#define ACTIVE_ON_HIGH 0 // Define si los botones están Activos en Alto (1) o Activos en Bajo (0)
// El shield tiene resistores pull-up, así que son Activos en Bajo.

#define CASA 1 // 1 para conectarse a la red de casa, 0 para conectarse a la red del dojo.

#endif // CONFIG_H

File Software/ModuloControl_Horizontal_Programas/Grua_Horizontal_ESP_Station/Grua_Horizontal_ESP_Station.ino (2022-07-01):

/* Este sketch se programa en el ESP del módulo de control horizontal de la grúa
 *  
 *  This sketch demonstrates how to set up a simple HTTP-like server.
 *  The server will set a GPIO pin depending on the request
 *    http://server_ip/paro/0 will set the GPIO2 low,
 *    http://server_ip/paro/1 will set the GPIO2 high
 *    http://server_ip/izquierda/1
 *     http://server_ip/derecha/1
 *  server_ip is the IP address of the ESP8266 module, will be 
 *  printed to Serial when the module is connected.
 *  
 *  
 *  The ESP-01 board can be set as AP (no modem needed) or Station (Modem needed).
 *  This is Station version. 
 *  
 *  Placa (ESP-01): 
 *  ESP8266 Boards (2.7.4) -> Generic ESP8266 Module  
 */

#include <ESP8266WiFi.h>
// GPIO 0 y 2 son normalmente altos, así que se usará lógica con activo en bajo.
// NOTA: Poner el pin INV del puente MC33 en alto (puenteado con jumper) para que con IN1 e IN2 en alto, OUT1 y OUT2 estén en BAJO (GND).
#define pinIzquierda 0 //GPIO0 
#define pinDerecha 2  //GPIO2

//En caso de que no se use I2C ni UART, Tx y Rx pueden usarse como GPIO's (GPIO1 y GPIO3)
//#define limiteIzq 1   
//#define limiteDer 3

const char* ssid = "GomezTorres";
const char* password = "lucy1nthesky";

#define DEBUG_MOVIMIENTO 1
#define DEBUG_COM 1
#define ACTIVE_ON_HIGH 1 //Logic for the DC driver.

// Create an instance of the server
// specify the port to listen on as an argument
WiFiServer server(80);
WiFiClient client;

int flag_ParoEmerg = 0;

// Dirección actual de la grúa.
boolean flagMoverIzq = 0, flagMoverDer = 0;
int valorLimiteIzq, valorLimiteDer;
String req, s;

// Variables to stop when no client available (safety reasons)
unsigned int contNoClient = 0; 
unsigned int delayNoClient = 50; // ms
unsigned int delayClientNoAvailable = 5; // ms
unsigned int delayLoopClient = 10; // ms
unsigned int maxTiempoActivo = 3000;// ms
unsigned int umbralContNoClient = maxTiempoActivo / delayNoClient;


void setup() {
  Serial.begin(115200);
  
  /* The pin configuration is for MC33296 driver correspondence*/
    // Configurar GPIO0 y GPIO2
  pinMode(pinIzquierda, OUTPUT);
  pinMode(pinDerecha, OUTPUT);
  
  #if ACTIVE_ON_HIGH
    digitalWrite(pinIzquierda, LOW);
    digitalWrite(pinDerecha, LOW);
  #else // Active on LOW.
    digitalWrite(pinIzquierda, HIGH); // Activo en BAJO, inactivo en ALTO.
    digitalWrite(pinDerecha, HIGH);
  #endif  

  delay(10); 
  // Pines para los limits switch //(Tx y Rx).
  // Configurar GPIO1
  // pinMode(limiteIzq, INPUT);
  // Configurar GPIO3
  // pinMode(limiteDer, INPUT);
  
  
  // Connect to WiFi network
  Serial.println();
  Serial.print("Conectando a ");
  Serial.println(ssid);
  
  WiFi.begin(ssid, password);
  
  while (WiFi.status() != WL_CONNECTED) 
  {
    delay(500);
    Serial.print(".");
  }
  Serial.println("");
  Serial.println("WiFi conectado\n\n");
  
  // Start the server
  server.begin();
  Serial.println("Servidor inicializado");

  // Print the IP address
  Serial.println(WiFi.localIP());

  Serial.print("Maximo tiempo Activo: ");
  Serial.println(maxTiempoActivo);
 
  Serial.print("Umbral Contador No Client: ");
  Serial.println(umbralContNoClient);
  
  delay(1500); 
}

void controlMotor()
{
  // The rest of the code use Active on High Logic for readability, only here in inverted 
  // when the Active on High logic is activated.
  #if ACTIVE_ON_HIGH
    
  #else
    // Aplicar lógica de activo en bajo.
    flagMoverIzq = !flagMoverIzq;
    flagMoverDer = !flagMoverDer;
  #endif
  
  // Set GPIO0 de acuerdo a la solicitud y Paro de Emergencia
  digitalWrite(pinIzquierda, flagMoverIzq);
  //Serial.print("flagDirIzq: "); Serial.println(flagMoverIzq);
  
  // Set GPIO2 de acuerdo a la solicitud y Paro de Emergencia
  digitalWrite(pinDerecha, flagMoverDer);
  //Serial.print("flagDirDer: "); Serial.println(flagMoverDer);
}


void loop() 
{  
  //valorLimiteIzq = digitalRead(limiteIzq); // Normalmente HIGH. LOW cuando se activan.
  //valorLimiteDer = digitalRead(limiteDer);

  // Check if a client has connected
  client = server.available();

  if (!client)
  {
    // Si no hay cliente conectado detener el movimiento del motor.
    contNoClient++;
    if(contNoClient == umbralContNoClient)
    {
    
      #if DEBUG_COM
        Serial.println("Deteniendo por !client");
      #endif
      
      flagMoverIzq = 0; 
      flagMoverDer = 0;
      
      controlMotor();  
      //contNoClient = 0; // Esta se reinicia cuando haya un nuevo cliente.
    }
    
    delay(delayNoClient);
    return; // Volver a iniciar el loop().
  }

#if DEBUG_COM
  //Serial.println("New client");
#endif  

  // Wait until the client sends some data  
  while(!client.available())
  {
    delay(delayClientNoAvailable); 
    
    #if DEBUG_COM
      Serial.println("!client.availble()");
    #endif
  }

  contNoClient = 0;  
  
  // Read the first line of the request
  req = client.readStringUntil('\r'); // Leer hasta salto de línea.
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

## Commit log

2022-07-01 Creación del repositorio
    [Circuito.fzz, ControlPad_Inferior_v3.stl, Cubierta_Control_Inferior.FCStd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]
2022-08-13 Se agregó la versión con NodeMCU Mini D1. Se hicieron modificaciones para seleccionar la red a conectar con un define. Se implementó comunicación TCP en todos los módulos.
    [Sujeta_motor_grua_editada.SLDPRT, Sujeta_motor_grua_editada.STL]
2023-09-27 Modificaciones para pad de control que soporta ESP8266 en el código (aún no es intercambiable con el ESP32, faltan cambios al circuito)
    [Circuito.fzz, CircuitoControlGrua.fzz, CircuitoControlGrua.sch]
2023-10-18 Actualización del README.md y cambio de nombre de algunas carpetas
    [Akoui-Pad-Control-Circuit.fzz, CircuitoControlGrua.fzz, CircuitoControlGrua.sch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]
